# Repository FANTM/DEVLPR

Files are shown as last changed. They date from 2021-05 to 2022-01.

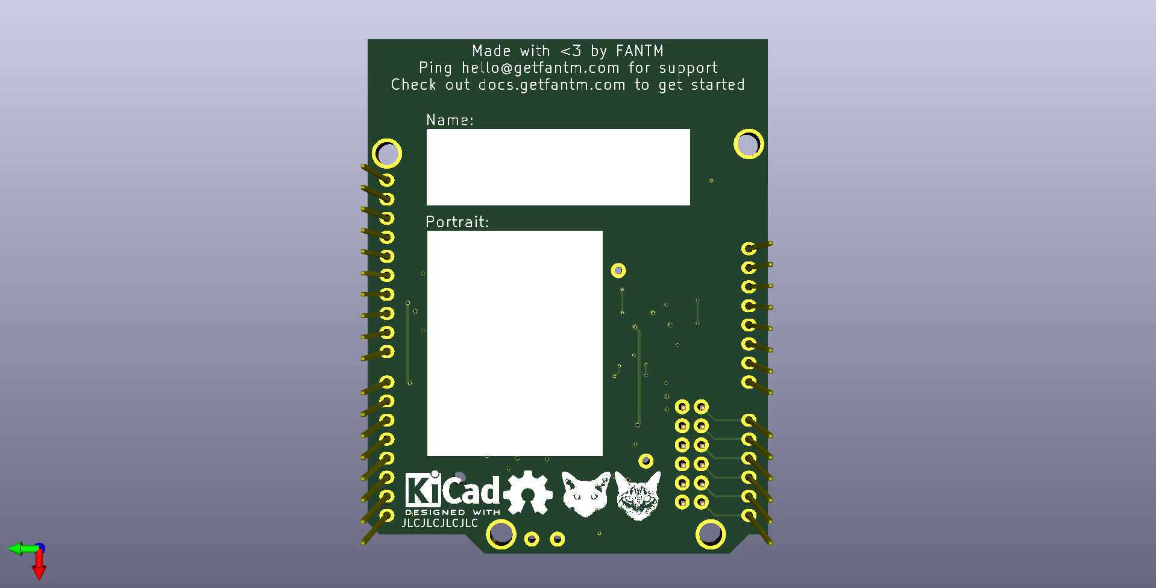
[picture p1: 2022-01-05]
DEVLPR.png

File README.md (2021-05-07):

# DEVLPR
DEVLPR

## About
zebra_fantm_gradient_bluepink 
[FANTM](https://getfantm.com) is creating easy-to-use EMG (muscle-based) interfaces for you and your computer. The DEVLPR is an Arduino shield that will make it so that you too can start playing around with EMG and all of the possibilities it opens up, whether it be for games, robotics, or something we've never thought of. Once we have the hardware in a functional state we plan on adding software libraries to make the device plug-and-play with Arduino and make it easy for the DEVLPR to be integrated into other projects. 

We're just two engineers who have a passion for new tech and Open Source, so share and build away!

## Disclaimer
This hardware is a major work in progress right now. We are still mid development cycle, and the board in its current state likely does not work. Once it is in a stable state we will tag a release but until then it's going to be frequently changing (and improving).

## Getting Started
This library relies on digikeys KiCAD symbol/footprint library, and they have been included as a submodule. This means when cloning with `git clone --recurse-submodules https://github.com/FANTM/DEVLPR`. If something goes wrong, the [git submodules documentation](https://git-scm.com/book/en/v2/Git-Tools-Submodules) is always helpful.

## License Information
This is an Open Source project and as such is licensed under CC. 

  <br />This work is licensed under a <a rel="license" href="http://creativecommons.org/licenses/by-sa/4.0/">Creative Commons Attribution-ShareAlike 4.0 International License</a>.

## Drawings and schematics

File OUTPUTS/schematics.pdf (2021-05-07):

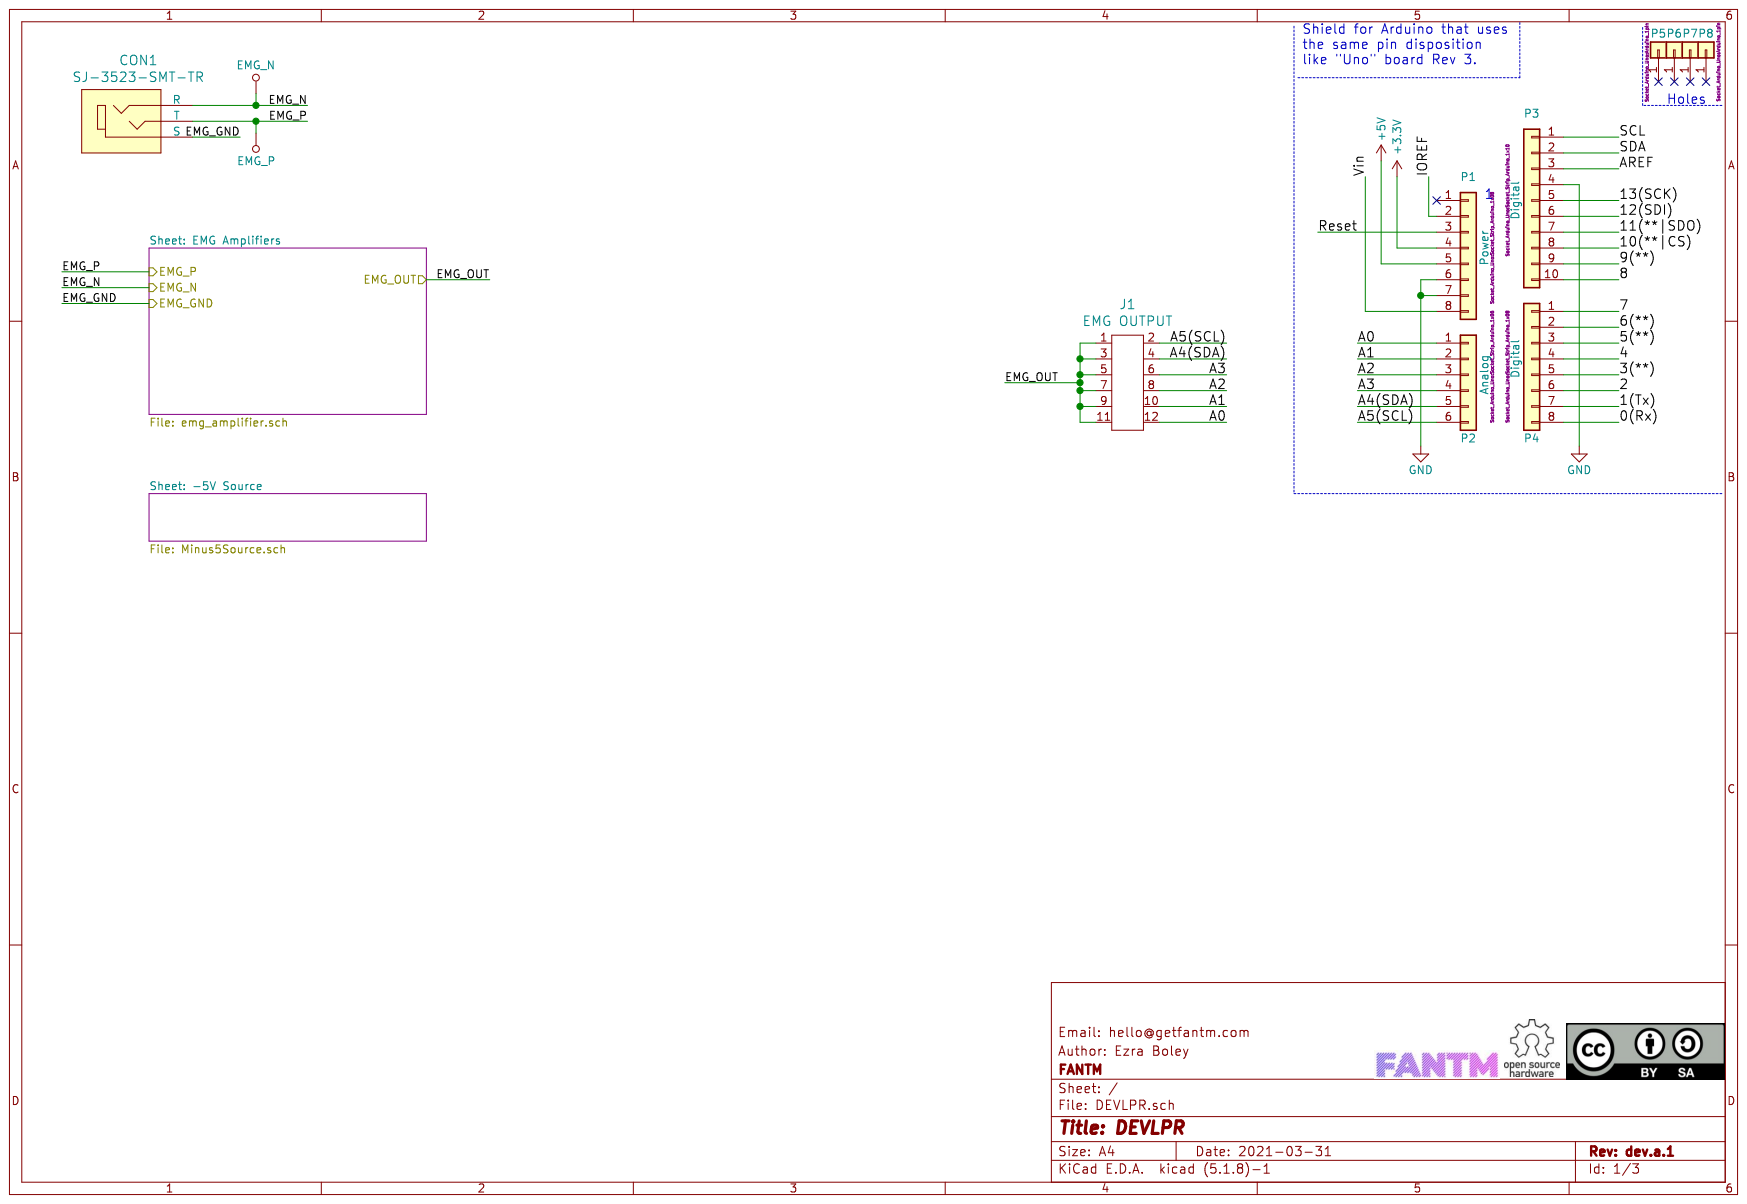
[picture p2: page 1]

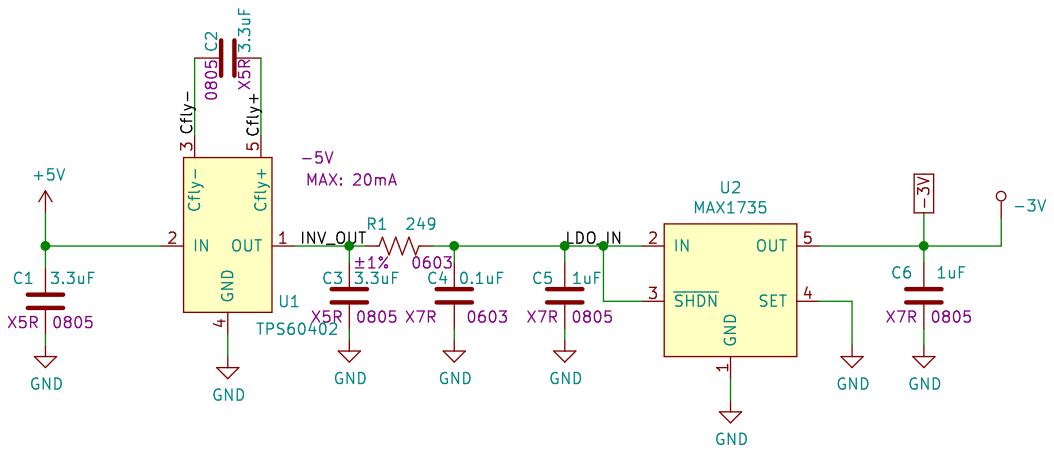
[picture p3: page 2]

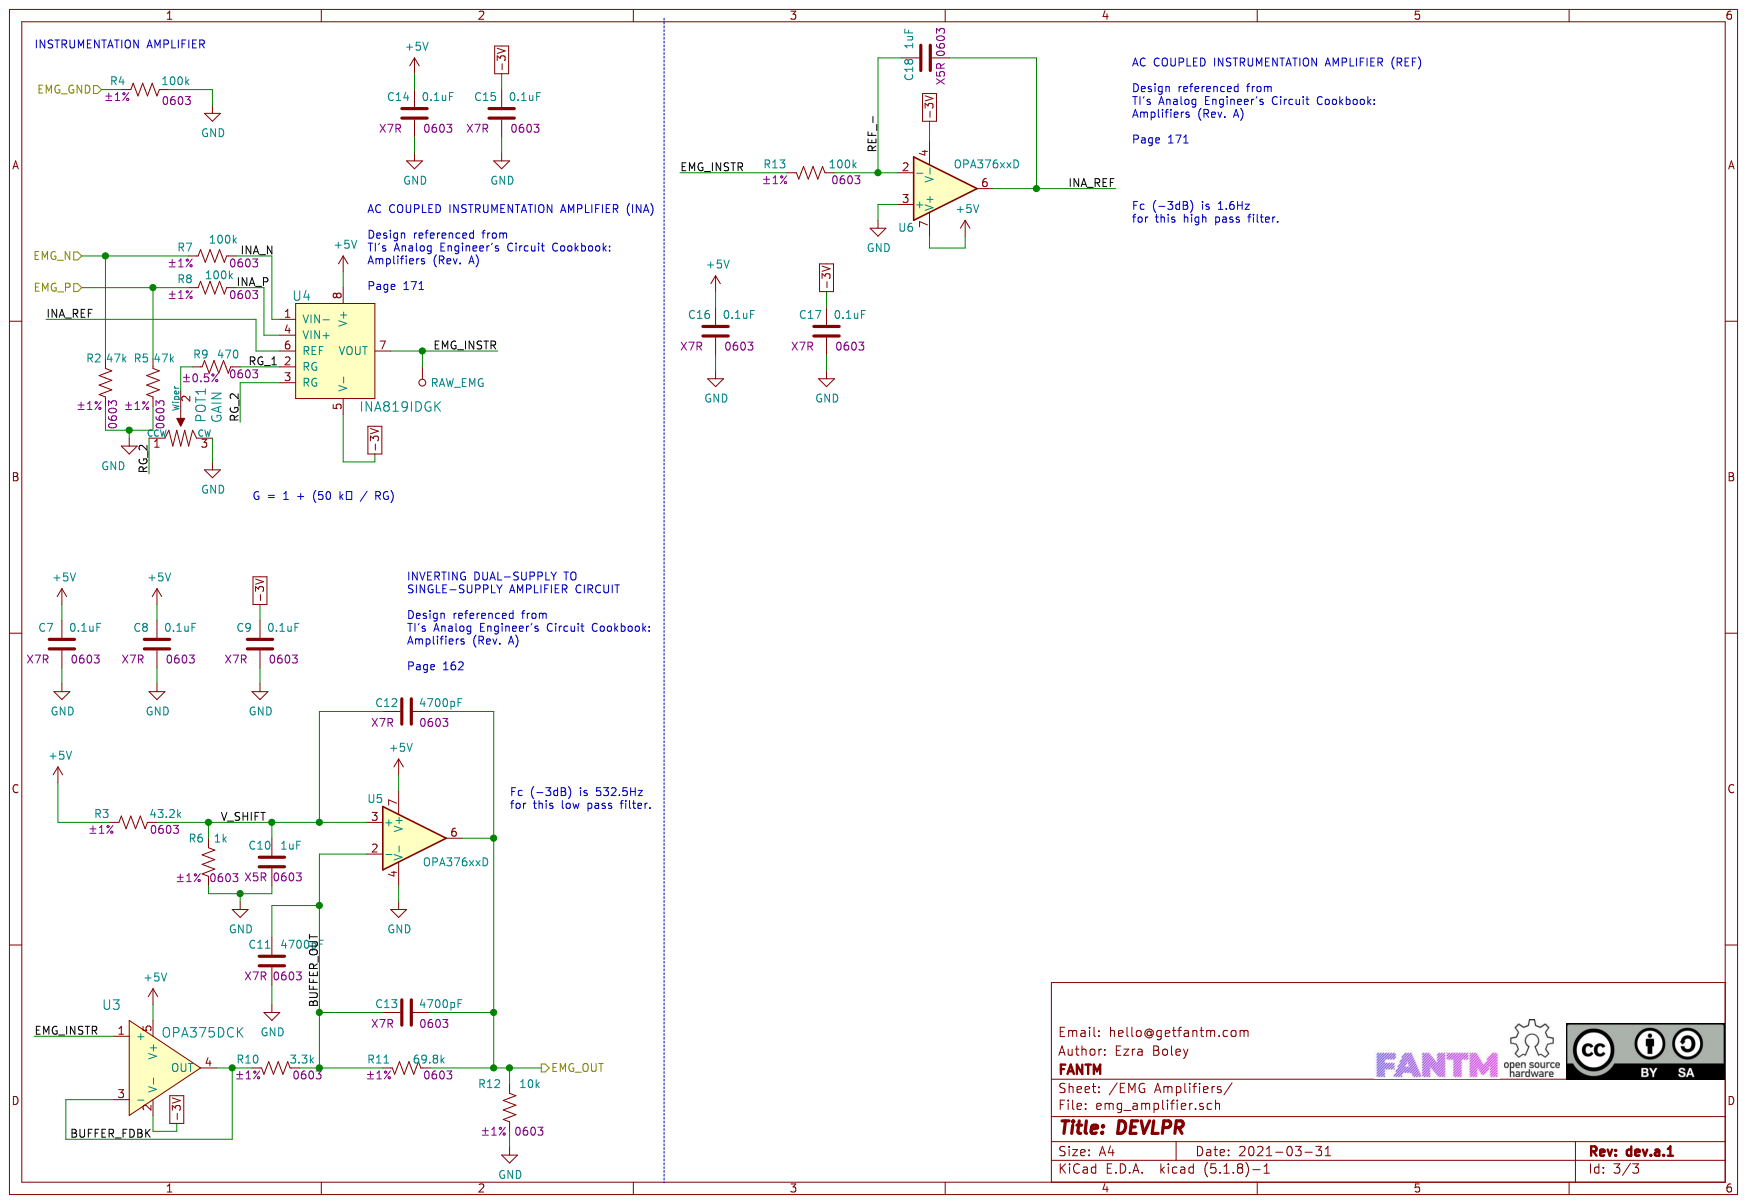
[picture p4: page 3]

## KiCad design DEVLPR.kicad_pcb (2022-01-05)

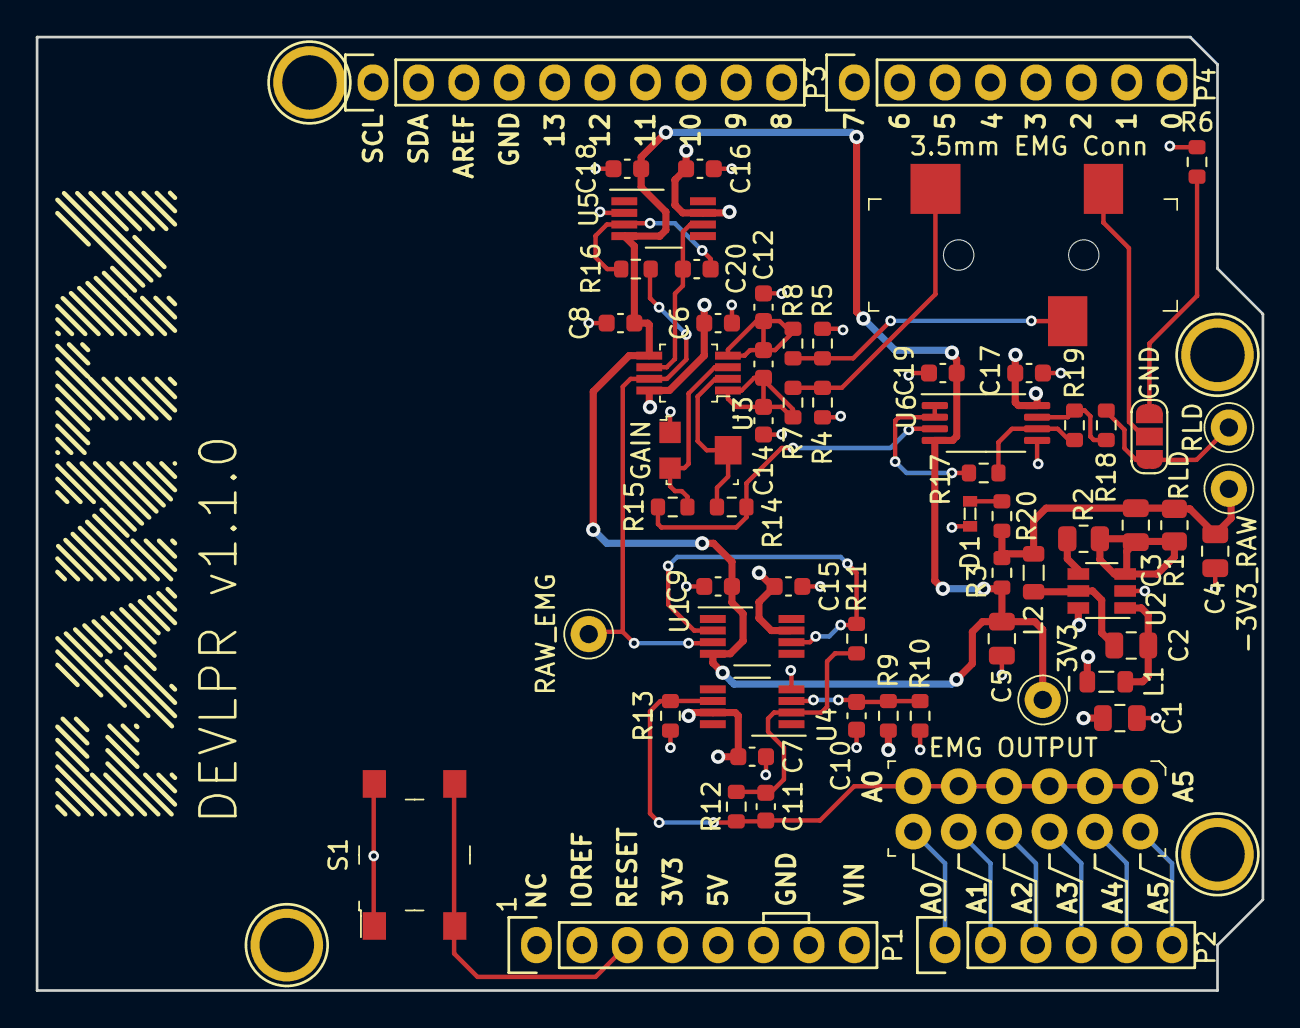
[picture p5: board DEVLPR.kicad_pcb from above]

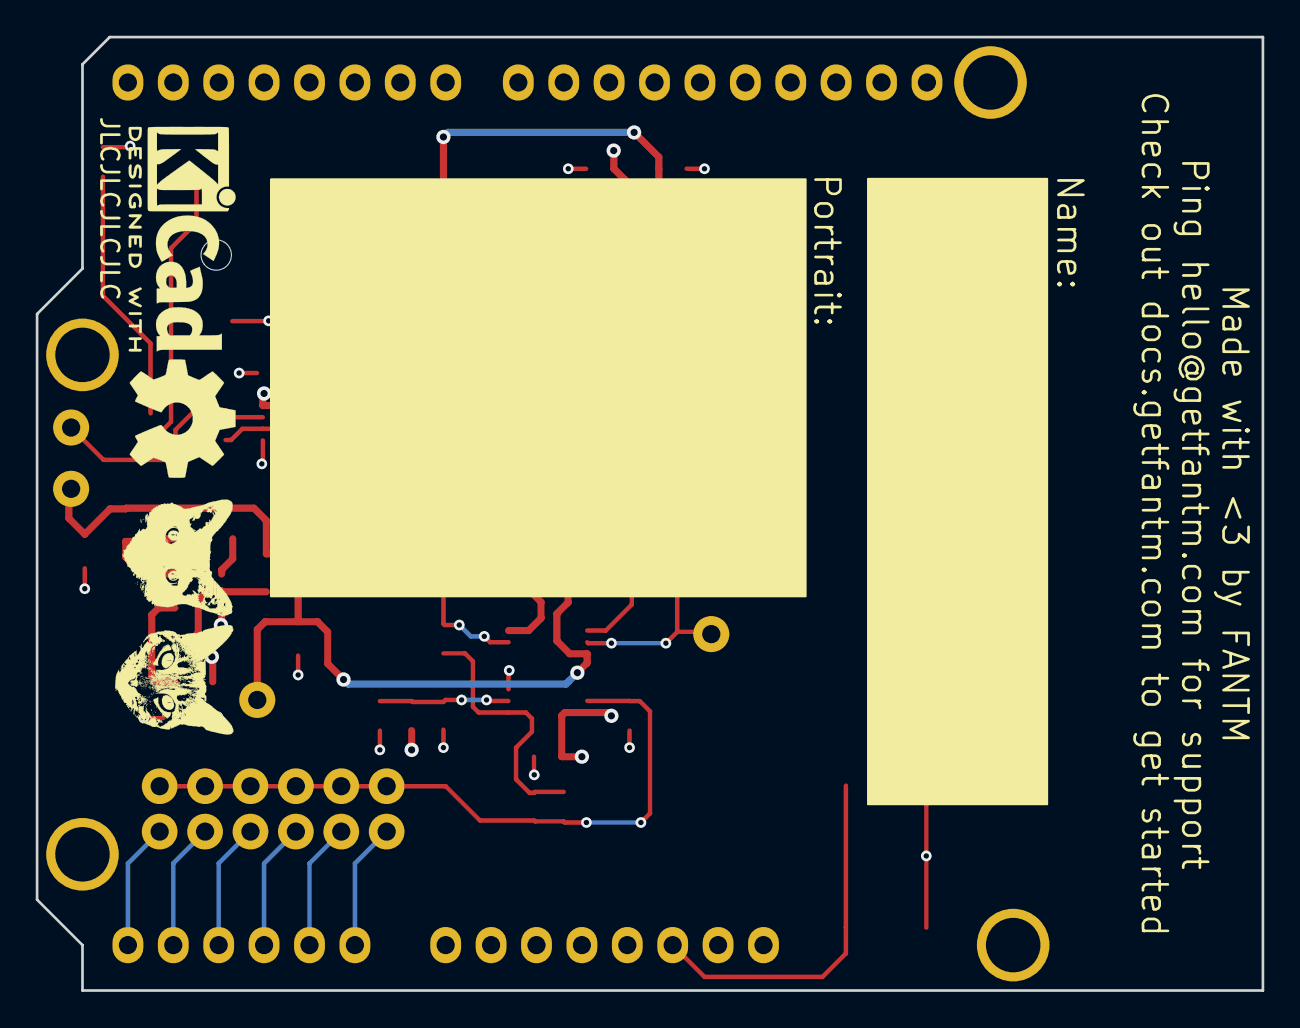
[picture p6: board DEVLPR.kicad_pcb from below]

Board: 4 copper layers, 68.6 x 53.3 mm, 72 parts (6 on the bottom side), 36 nets.

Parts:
C1, C2: 1uF; C_0805_2012Metric
C3: 22pF; C_0805_2012Metric
C4: 4.7uF; C_0805_2012Metric
C5: 10uF; C_0805_2012Metric
C6, C7, C8, C9, C15, C16, C17, C18, C19: 0.1uF; C_0603_1608Metric
C10, C20: 1uF; C_0603_1608Metric
C11: 4700pF; C_0603_1608Metric
C12, C14: 2.2pF; C_0603_1608Metric
C13: 10pF; C_0603_1608Metric
CON1: SJ-3523-SMT-TR; Switch_Slide_11.6x4mm_SJ-3523-SMT
D1: GREEN LED; 0603
J1: EMG OUTPUT; PinHeader_6x2_P2.54mm_Horizontal
JP1: RLD_SEL; SolderJumper-3_P1.3mm_Open_RoundedPad1.0x1.5mm_NumberLabels
L1, L2: 10uH; L_0805_2012Metric
P1: Power; Socket_Strip_Arduino_1x08
P2: Analog; Socket_Strip_Arduino_1x06
P3: Digital; Socket_Strip_Arduino_1x10
P4: Digital; Socket_Strip_Arduino_1x08
P5, P6, P7, P8: CONN_01X01; Arduino_1pin
POT1: GAIN; Trimpot_3.8mmx3.6mm_TC33X-2-103E
R1: 267k; R_0805_2012Metric
R2: 102k; R_0805_2012Metric
R3: 249; R_0603_1608Metric
R4, R5: 47k; R_0603_1608Metric
R6, R7, R8, R16, R18, R19: 100k; R_0603_1608Metric
R9: 68k; R_0603_1608Metric
R10, R11, R13, R17: 10k; R_0603_1608Metric
R12: 28.7k; R_0603_1608Metric
R14, R15: 470; R_0603_1608Metric
R20: 1k; R_0603_1608Metric
S1: PTS645SM43SMTR92_LFS; Switch_Tactile_SMD_6x6mm_PTS645
S2: Linus; linus_xsm
S3: Sinclair; sin_ham_bitmap_sm
S4: Kicad; KiCad-Logo2_5mm_SilkScreen
S5: OSHW; OSHW-Symbol_6.7x6mm_SilkScreen
S6: Portrait; portait
S7: Name; name
TP1: -3V3_RAW; Test_Point_D1.02mm
TP2: -3V3; Test_Point_D1.02mm
TP3: RAW_EMG; Test_Point_D1.02mm
TP4: RLD; Test_Point_D1.02mm
U1, U4, U5: OPA187IDR; VSSOP-8_3.0x3.0mm_P0.65mm
U2: LT3462A; TSOT-23-6
U3: INA821IDGKT; TSSOP-8_W3mm
U6: OPA2375IPWR; TSSOP-8_4.4x3mm_P0.65mm

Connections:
+3V3: C1.1, C6.2, C7.2, C15.2, C16.2, C17.2, L1.1, P1.4, R9.1, U1.7, U2.6, U3.8, U4.7, U5.7, U6.8
-3V3: C5.1, C8.2, C9.2, C18.2, C19.2, R3.1, TP2.1, U1.4, U3.5, U5.4, U6.4
/-3V3 Source/-3V3_D: C2.1, L2.1, U2.5
/-3V3 Source/-3V3_FB: C3.2, R1.2, R2.2, U2.3
/-3V3 Source/-3V3_RAW: C3.1, C4.1, L2.2, R1.1, R3.2, R20.1, TP1.1
/-3V3 Source/-3V3_SDREF: R2.1, U2.4
/-3V3 Source/-3V3_SW: C2.2, L1.2, U2.1
/A0: J1.12, P2.1
/A1: J1.10, P2.2
/A2: J1.8, P2.3
/A3: J1.6, P2.4
/A4(SDA): J1.4, P2.5
/A5(SCL): J1.2, P2.6
/EMG Amplifiers/BUFF_FDBK: R11.2, U1.2, U1.6
/EMG Amplifiers/BUFF_MID: C11.1, R11.1, R12.2, U4.2
/EMG Amplifiers/EMG_INSTR: R16.2, TP3.1, U1.3, U3.7
/EMG Amplifiers/GND_REF: JP1.3, R6.1
/EMG Amplifiers/INA_N: C13.1, C14.2, R7.2, U3.1
/EMG Amplifiers/INA_P: C12.1, C13.2, R8.2, U3.4
/EMG Amplifiers/INA_REF: C20.1, U3.6, U5.6
/EMG Amplifiers/REF_-: C20.2, R16.1, U5.3
/EMG Amplifiers/RG1: POT1.2, R14.2, U3.2
/EMG Amplifiers/RG2: POT1.3, R15.1, U3.3
/EMG Amplifiers/RLD: JP1.1, R18.2, TP4.1
/EMG Amplifiers/RLD_IN: R14.1, R15.2, U6.3
/EMG Amplifiers/RLD_IN2_-: R17.1, R19.2, U6.6
/EMG Amplifiers/RLD_MID: R17.2, U6.1, U6.2
/EMG Amplifiers/RLD_OUT2: R18.1, R19.1, U6.7
/EMG Amplifiers/V_SHIFT: C10.2, R9.2, R10.1, U4.3
/EMG_GND: CON1.1, JP1.2
/EMG_N: CON1.2, R4.2, R7.1
/EMG_OUT: C11.2, J1.1, J1.3, J1.5, J1.7, J1.9, J1.11, R12.1, R13.1, U4.6
/EMG_P: CON1.3, R5.2, R8.1
/Reset: P1.3, S1.3, S1.4
GND: C1.2, C4.2, C5.2, C6.1, C7.1, C8.1, C9.1, C10.1, C12.2, C14.1, C15.1, C16.1, C17.1, C18.1, C19.1, D1.1, P1.6, P1.7, P3.4, POT1.1, R4.1, R5.1, R6.2, R10.2, R13.2, S1.1, S1.2, U2.2, U4.4, U5.2, U6.5
unnamed: D1.2, R20.2

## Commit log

2021-04-01 Initial commit with current progress
    [Minus5Source.sch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]
2021-04-01 Fixed naming and cleaned up libraries
    [DEVLPR.kicad_pcb, DEVLPR.sch, emg_amplifier.sch]
2021-04-07 Adding the LP filter to the level shifter
    [Minus5Source.sch, emg_amplifier.sch]
2021-04-08 Finalized rev dev.a.2 with improved filtering, power supply design, and silkscreen
    [DEVLPR-B_Cu.gbr, DEVLPR-B_Mask.gbr, DEVLPR-B_SilkS.gbr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]
2021-04-22 Major overhaul given chip shortage. Completely redid the power supply, and refined the amps for the EMG to give better gain and use the full output range
    [DEVLPR.kicad_pcb, DEVLPR.sch, Minus5Source.sch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]
2021-04-22 Fixed SPI signal naming convention to new OSHWA proposal
    [DEVLPR.kicad_pcb, DEVLPR.sch, Minus5Source.sch]
2021-05-07 Finished rev dev.a.4 with safety improvements, better gain settings, and dc offset removal
    [DEVLPR-B_Cu.gbl, DEVLPR-B_Mask.gbs, DEVLPR-B_Paste.gbp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]
2021-06-23 Stupidly named the voltage source and then didn't change it when the V changed
    [DEVLPR.sch, Minus3Source.sch, Minus5Source.sch]
2022-01-05 Created v1.1 of the DEVLPR, adding RLD
    [DEVLPR-B_Cu.gbl, DEVLPR-B_Mask.gbs, DEVLPR-B_Paste.gbp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]
